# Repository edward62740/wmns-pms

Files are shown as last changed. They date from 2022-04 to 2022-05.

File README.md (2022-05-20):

# Particulate Matter Sensor

This sensor measures particulate matter in the air, shows readings on a display and posts the data to InfluxDB. Extention of [WMNS](https://github.com/edward62740/Wireless-Mesh-Network-System).

20220520_093548-removebg-preview

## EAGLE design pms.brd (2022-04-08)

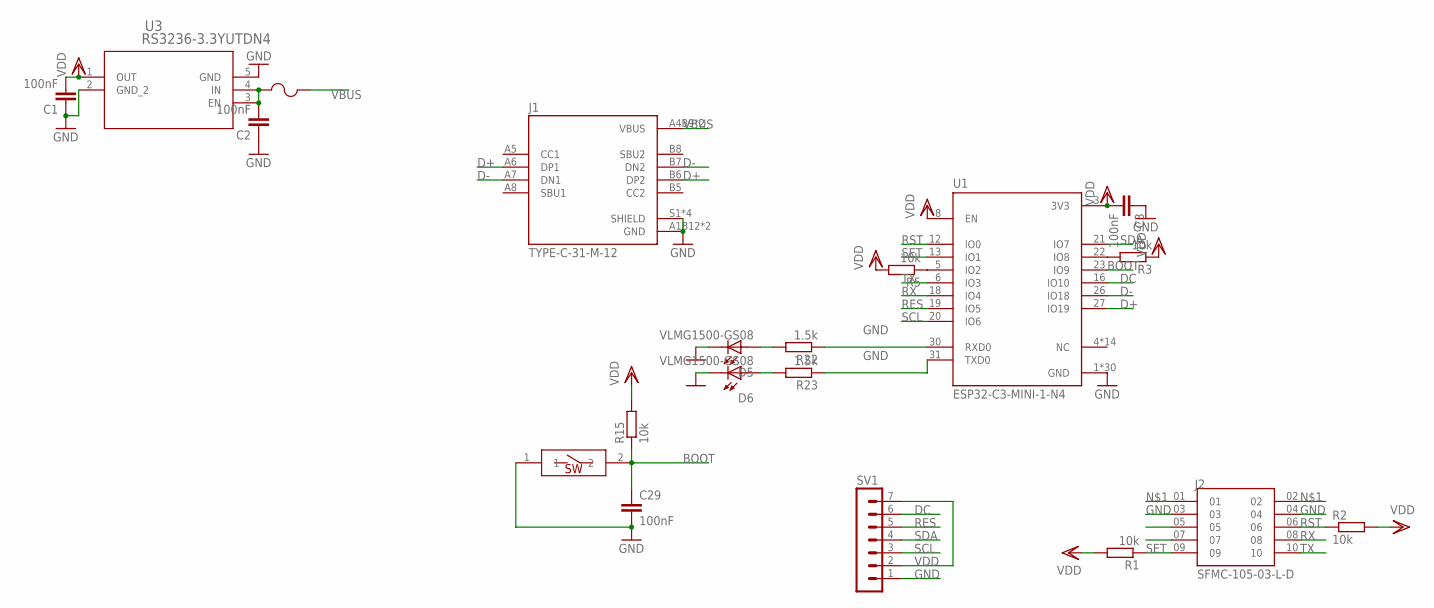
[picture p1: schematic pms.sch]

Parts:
C1, C2, C3, C29: 100nF; C0402
D5, D6: VLMG1500-GS08; LEDC1005X35N
F2: 1210L050YR1210LSERIES_LTF-L; 1210LSERIES_LTF-L
J1: TYPE-C-31-M-12; HRO_TYPE-C-31-M-12
J2: SFMC-105-03-L-D; SAMTEC_SFMC-105-03-L-D
R1, R2, R3, R5, R15: 10k; R0402
R22, R23: 1.5k; R0402
RESET: SMDSWITCH; RESC4217X170
SV1: MA07-1
U1: ESP32-C3-MINI-1-N4; XCVR_ESP32-C3-MINI-1-N4
U3: RS3236-3.3YUTDN4; UTDFN-1X1-4_JRT

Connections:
BOOT: C29.1, R15.1, RESET.2, U1.23 (IO9)
D+: J1.A6 (DP1), J1.B6 (DP2), U1.27 (IO19)
D-: J1.A7 (DN1), J1.B7 (DN2), U1.26 (IO18)
DC: SV1.6, U1.16 (IO10)
GND: C1.1, C2.1, C3.1, C29.2, D5.2, D6.2, J1.A1B12 (GND), J1.B1A12 (GND), J1.S1 (SHIELD), J1.S2 (SHIELD), J1.S3 (SHIELD), J1.S4 (SHIELD), J2.03, J2.04, RESET.1, SV1.1, U1.1 (GND), U1.2 (GND), U1.11 (GND), U1.14 (GND), U1.36 (GND), U1.37 (GND), U1.38 (GND), U1.39 (GND), U1.40 (GND), U1.41 (GND), U1.42 (GND), U1.43 (GND), U1.44 (GND), U1.45 (GND), U1.46 (GND), U1.47 (GND), U1.48 (GND), U1.49_1 (GND), U1.49_2 (GND), U1.49_3 (GND), U1.49_4 (GND), U1.49_5 (GND), U1.49_6 (GND), U1.49_7 (GND), U1.49_8 (GND), U1.49_9 (GND), U1.50 (GND), U1.51 (GND), U1.52 (GND), U1.53 (GND), U3.2 (GND_2), U3.5 (GND)
unnamed: C2.2, F2.2, J2.01, J2.02, U3.3 (EN), U3.4 (IN)
unnamed: R3.2, U1.22 (IO8)
unnamed: R5.1, U1.5 (IO2)
unnamed: R23.1, U1.31 (TXD0)
unnamed: R22.1, U1.30 (RXD0)
unnamed: D5.1, R22.2
unnamed: D6.1, R23.2
RES: SV1.5, U1.19 (IO5)
RST: J2.06, R2.1, U1.12 (IO0)
RX: J2.08, U1.18 (IO4)
SCL: SV1.3, U1.20 (IO6)
SDA: SV1.4, U1.21 (IO7)
SET: J2.09, R1.1, U1.13 (IO1)
TX: J2.10, U1.6 (IO3)
VBUS: F2.1, J1.A4B9 (VBUS), J1.B4A9 (VBUS)
VDD: C1.2, C3.2, R1.2, R2.2, R3.1, R5.2, R15.2, SV1.2, SV1.7, U1.3 (3V3), U1.8 (EN), U3.1 (OUT)

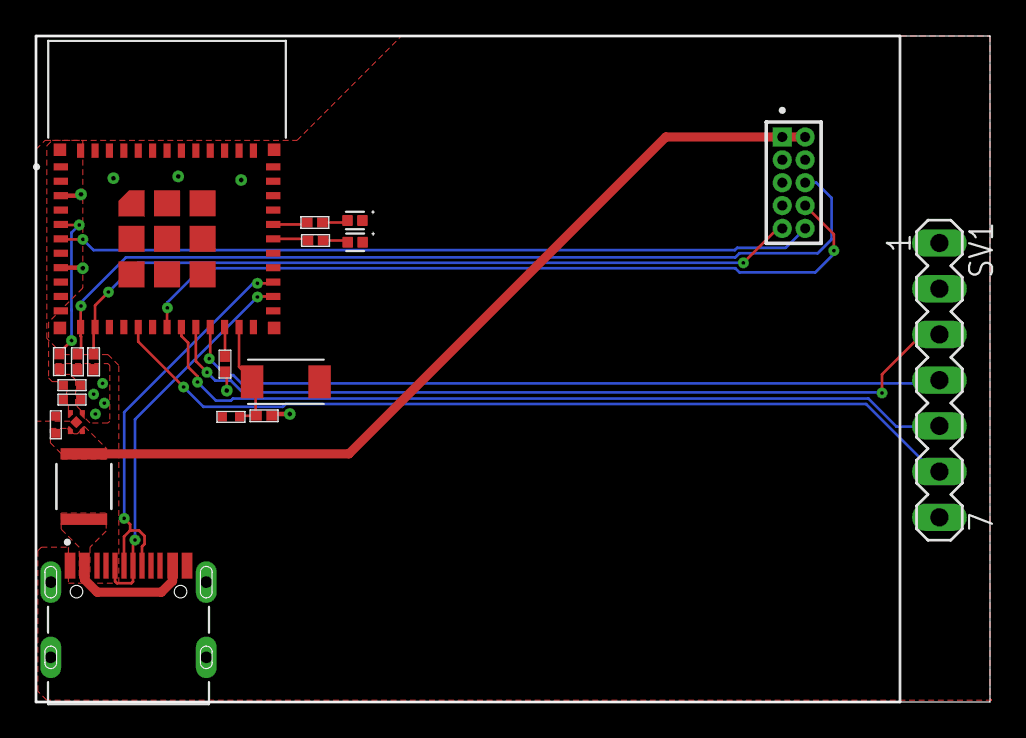
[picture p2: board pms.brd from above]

Board: 4 copper layers, 53.0 x 37.0 mm, 20 parts (0 on the bottom side), 21 nets.

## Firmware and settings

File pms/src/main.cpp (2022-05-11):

#include <PMserial.h> // Arduino library for PM sensors with serial interface
#include "Arduino_ST7789.h"
#include "Adafruit_GFX.h"
#include <WiFi.h>
#include <InfluxDbClient.h>
#include <InfluxDbCloud.h>
#include "Fonts/FreeSansBold18pt7b.h"
#include "Fonts/FreeSansBold12pt7b.h"
#include "Fonts/FreeSansBold9pt7b.h"

String hostname = "";
/* InfluxDB Connection Parameters */
#define WIFI_SSID ""
#define WIFI_PASSWORD ""

#define INFLUXDB_URL ""
// InfluxDB v2 server or cloud API authentication token (Use: InfluxDB UI -> Data -> Tokens -> <select token>)
#define INFLUXDB_TOKEN ""
// InfluxDB v2 organization id (Use: InfluxDB UI -> User -> About -> Common Ids )
#define INFLUXDB_ORG ""
// InfluxDB v2 bucket name (Use: InfluxDB UI ->  Data -> Buckets)
#define INFLUXDB_BUCKET ""
#define TZ_INFO ""

/* InfluxDB Data Points */
Point PMS("PMS");

struct pms_struct
{
  uint16_t pm01 = 0;
  uint16_t pm25 = 0;
  uint16_t pm10 = 0;
  uint16_t n0p3 = 0;
  uint16_t n0p5 = 0;
  uint16_t n1p0 = 0;
  uint16_t n2p5 = 0;
  uint16_t n5p0 = 0;
  uint16_t n10p0 = 0;
  uint32_t ERR_COUNT = 0;
} pms_data;
constexpr auto PMS_RX = 3;
constexpr auto PMS_TX = 4;
Arduino_ST7789 tft = Arduino_ST7789(10, 5, 7, 6, 2);
SerialPM pms(PMS7003, PMS_RX, PMS_TX); // PMSx003, RX, TX
InfluxDBClient client(INFLUXDB_URL, INFLUXDB_ORG, INFLUXDB_BUCKET, INFLUXDB_TOKEN, InfluxDbCloud2CACert);
void setup()
{
  Serial.begin(115200);
  tft.init(240, 240);

  tft.fillScreen(BLUE);
  tft.fillRect(0, 126, 240, 114, BLACK);
  tft.setFont(&FreeSansBold9pt7b);
  tft.setCursor(1, 20);
  tft.print("Particulate Matter Readings");
  tft.setCursor(0, 140);
  tft.print("Dust Bin Count / m");
  tft.setCursor(162, 137);
  tft.print("3");
  tft.setFont(&FreeSansBold18pt7b);
  tft.setTextColor(BLACK);
  tft.setCursor(0, 55);
  tft.print("PM");
  tft.setCursor(0, 85);
  tft.print("PM");
  tft.setCursor(0, 115);
  tft.print("PM");
  tft.setFont(&FreeSansBold12pt7b);
  tft.setCursor(53, 58);
  tft.print("1");
  tft.setCursor(53, 85);
  tft.print("2.5");
  tft.setCursor(56, 118);
  tft.print("10");
  tft.setTextColor(GREEN);
  tft.setCursor(0, 238);
  tft.print("0.3");
  tft.setCursor(40, 238);
  tft.print("0.5");
  tft.setCursor(83, 238);
  tft.print("1.0");
  tft.setCursor(130, 238);
  tft.print("2.5");
  tft.setCursor(175, 238);
  tft.print("5");
  tft.setCursor(200, 238);
  tft.print("10");
  tft.setFont(&FreeSansBold18pt7b);
  tft.setTextColor(RED);
  tft.setCursor(120, 55);
  tft.print("...");
  tft.setTextColor(MAGENTA);
  tft.setCursor(120, 85);
  tft.print("...");
  tft.setTextColor(YELLOW);
  tft.setCursor(120, 115);
  tft.print("...");
  pms.init();

  WiFi.begin(WIFI_SSID, WIFI_PASSWORD);
  while (WiFi.status() != WL_CONNECTED)
  {
    Serial.println("[INIT] ERROR CONNECTING TO WIFI");
    WiFi.disconnect();
    WiFi.begin(WIFI_SSID, WIFI_PASSWORD);
    delay(3500);
  }
  configTzTime("SGT-8", "pool.ntp.org", "time.nis.gov");
  client.setHTTPOptions(HTTPOptions().httpReadTimeout(200));
  client.setHTTPOptions(HTTPOptions().connectionReuse(true));
  // Check server connection
  if (client.validateConnection())
  {
    Serial.print("Connected to InfluxDB: ");
    Serial.println(client.getServerUrl());
  }
  else
  {
    Serial.print("InfluxDB connection failed: ");
    Serial.println(client.getLastErrorMessage());
  }
  Serial.println("[INIT] IFDB CONNECTION OK");
}

void loop()
{
  Serial.println("trs");
  pms.read();
  if (pms)
  {
    pms_data.pm01 = pms.pm01;
    pms_data.pm25 = pms.pm25;
    pms_data.pm10 = pms.pm10;
    pms_data.n0p3 = pms.n0p3;
    pms_data.n0p5 = pms.n0p5;
    pms_data.n1p0 = pms.n1p0;
    pms_data.n2p5 = pms.n2p5;
    pms_data.n5p0 = pms.n5p0;
    pms_data.n10p0 = pms.n10p0;
  }
  else
  {
  }

  PMS.clearFields();
  PMS.clearTags();
  PMS.addTag("UID", "N/A");
  PMS.addField("PM0.1", (pms_data.pm01));
  PMS.addField("PM2.5", (pms_data.pm25));
  PMS.addField("PM1.0", (pms_data.pm10));
  PMS.addField("N0.3", (pms_data.n0p3));
  PMS.addField("N0.5", (pms_data.n0p5));
  PMS.addField("N1.0", (pms_data.n1p0));
  PMS.addField("N2.5", (pms_data.n2p5));
  PMS.addField("N5.0", (pms_data.n5p0));
  PMS.addField("N10.0", (pms_data.n10p0));
  PMS.addField("Error Count", (pms_data.ERR_COUNT));
  if (!client.writePoint(PMS))
  {
    Serial.println("ERROR");
    pms_data.ERR_COUNT++;
  }
  tft.setFont(&FreeSansBold18pt7b);
  tft.fillRect(120, 25, 120, 30, BLUE);
  tft.setTextColor(RED);
  tft.setCursor(120, 55);
  tft.print(pms_data.pm01);
  tft.fillRect(120, 55, 120, 30, BLUE);
  tft.setTextColor(MAGENTA);
  tft.setCursor(120, 85);
  tft.print(pms_data.pm25);
  tft.fillRect(120, 85, 120, 33, BLUE);
  tft.setTextColor(YELLOW);
  tft.setCursor(120, 115);
  tft.print(pms_data.pm10);
  tft.setFont(&FreeSansBold9pt7b);
  tft.setTextColor(0xFC00);

  tft.fillRect(2, 150, 36, 70, 0x3838);
  tft.fillRect(2, 150, 36, (int16_t)((float)(10000 - pms_data.n0p3) * 0.007), BLACK);
  if ((int16_t)((float)(10000 - pms_data.n0p3) * 0.007) < 40)
  {
    tft.setCursor(2, 165 + (int16_t)((float)(10000 - pms_data.n0p3) * 0.007));
    tft.printf("%.1f", ((float)pms_data.n0p3 / 1000));
    tft.setCursor(27, 165 + (int16_t)((float)(10000 - pms_data.n0p3) * 0.007));
    tft.print("k");
  }
  else
  {
    tft.setCursor(2, 165 + (int16_t)40);
    tft.printf("%.1f", ((float)pms_data.n0p3 / 1000));
    tft.setCursor(27, 165 + (int16_t)40);
    tft.print("k");
  }

  tft.fillRect(42, 150, 36, 70, 0x3838);
  tft.fillRect(42, 150, 36, (int16_t)((float)(4000 - pms_data.n0p5) * 0.0175), BLACK);
  if ((int16_t)((float)(4000 - pms_data.n0p5) * 0.0175) < 40)
  {
    tft.setCursor(42, 165 + (int16_t)((float)(4000 - pms_data.n0p5) * 0.0175));
    tft.printf("%.1f", ((float)pms_data.n0p5 / 1000));
    tft.setCursor(67, 165 + (int16_t)((float)(4000 - pms_data.n0p5) * 0.0175));
    tft.print("k");
  }
  else
  {
    tft.setCursor(42, 165 + (int16_t)40);
    tft.printf("%.1f", ((float)pms_data.n0p5 / 1000));
    tft.setCursor(67, 165 + (int16_t)40);
    tft.print("k");
  }

  tft.fillRect(82, 150, 36, 70, 0x3838);
  tft.fillRect(82, 150, 36, (int16_t)((float)(700 - pms_data.n1p0) * 0.1), BLACK);
  if ((int16_t)((float)(700 - pms_data.n1p0) * 0.1) < 40)
  {

    tft.setCursor(82, 165 + (int16_t)((float)(700 - pms_data.n1p0) * 0.1));
    tft.print(pms_data.n1p0);
  }
  else
  {

    tft.setCursor(82, 165 + (int16_t)40);
    tft.print(pms_data.n1p0);
  }

  tft.fillRect(122, 150, 36, 70, 0x3838);
  tft.fillRect(122, 150, 36, (int16_t)((float)(100 - pms_data.n2p5) * 0.7), BLACK);
  if ((int16_t)((float)(100 - pms_data.n2p5) * 0.7) < 40)
  {

    tft.setCursor(122, 165 + (int16_t)((float)(100 - pms_data.n2p5) * 0.7));
    tft.print(pms_data.n2p5);
  }
  else
  {

    tft.setCursor(122, 165 + (int16_t)40);
    tft.print(pms_data.n2p5);
  }

  tft.fillRect(162, 150, 36, 70, 0x3838);
  tft.fillRect(162, 150, 36, (int16_t)((float)(20 - pms_data.n5p0) * 3.5), BLACK);
  if ((int16_t)((float)(20 - pms_data.n5p0) * 3.5) < 40)
  {
    tft.setCursor(162, 165 + (int16_t)((float)(20 - pms_data.n5p0) * 3.5));
    tft.print(pms_data.n5p0);
  }
  else
  {
    tft.setCursor(162, 165 + (int16_t)40);
    tft.print(pms_data.n5p0);
  }

  tft.fillRect(202, 150, 36, 70, 0x3838);
  tft.fillRect(202, 150, 36, (int16_t)((float)(10 - pms_data.n10p0) * 7), BLACK);
  if ((int16_t)((float)(10 - pms_data.n10p0) * 7) < 40)
  {
    tft.setCursor(202, 165 + (int16_t)((float)(10 - pms_data.n10p0) * 7));
    tft.print(pms_data.n10p0);
  }
  else
  {
    tft.setCursor(202, 165 + (int16_t)40);
    tft.print(pms_data.n10p0);
  }

  Serial.print("[IFDB] TXN ");
  delay(3500);
}

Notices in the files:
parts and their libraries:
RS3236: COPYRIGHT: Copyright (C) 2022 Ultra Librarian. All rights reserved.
